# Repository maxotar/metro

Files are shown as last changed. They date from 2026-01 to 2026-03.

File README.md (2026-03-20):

# Metro - Vibrating Metronome Wearable

A compact wearable metronome device that provides haptic feedback for keeping time. Perfect for musicians, dancers, and other performers who need portable tempo guidance.

## Project Metadata

- **Project Name:** Metro
- **Type:** Wearable Device
- **Primary Function:** Vibrating Metronome
- **Target MCU:** ATtiny1616
- **CPU Frequency:** 4 MHz
- **Battery:** 302025 LiPo
- **Charging:** Smart ring magnetic pogo pin connector

## Project Structure

### `/electrical`
PCB design files, schematics, and component information
- KiCad project files (.kicad_sch, .kicad_pcb)
- Component library with footprints and datasheets
- Fabrication and production files (BOM, designators, netlist)

### `/src`
Firmware for the ATtiny1616 microcontroller
- `main.cpp` - Main program entry point
- `i2c.cpp` - I2C communication library

### `/mechanical`
Enclosure and mechanical design
- `Case.step` - 3D model of the device case
- [Onshape CAD](https://cad.onshape.com/documents/80829a8af30c2a989428d6ff/w/00026b4066893ecc4d2da063/e/4930d11ba89da00962c1ae8d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) - Full source CAD file

**3D Printing Specifications:**
- Printer: Bambu Lab A1
- Material: Matte white PLA
- Bed: Smooth PEI surface
- Nozzle: 0.2 mm
- Layer height: 0.06 mm (high quality)
- Print method: Parts printed individually (case, back cap, buttons) for quality assurance

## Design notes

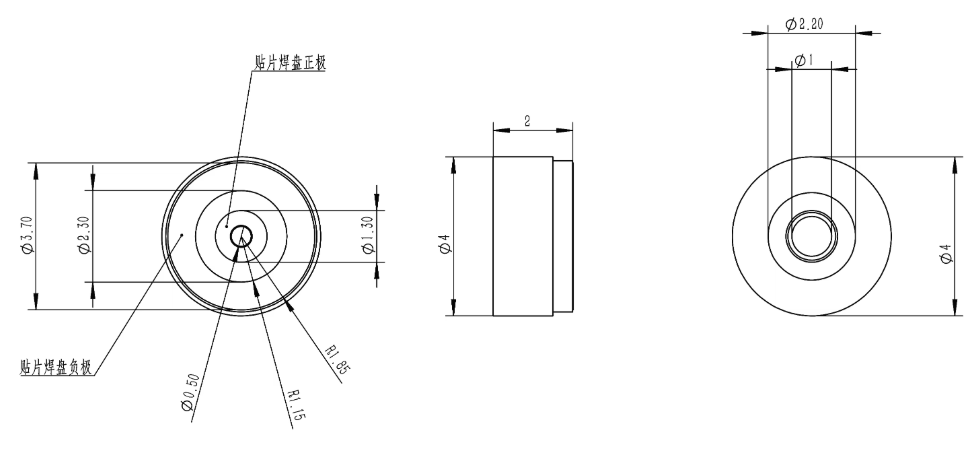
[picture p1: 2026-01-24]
mechanical/Power Connector.PNG

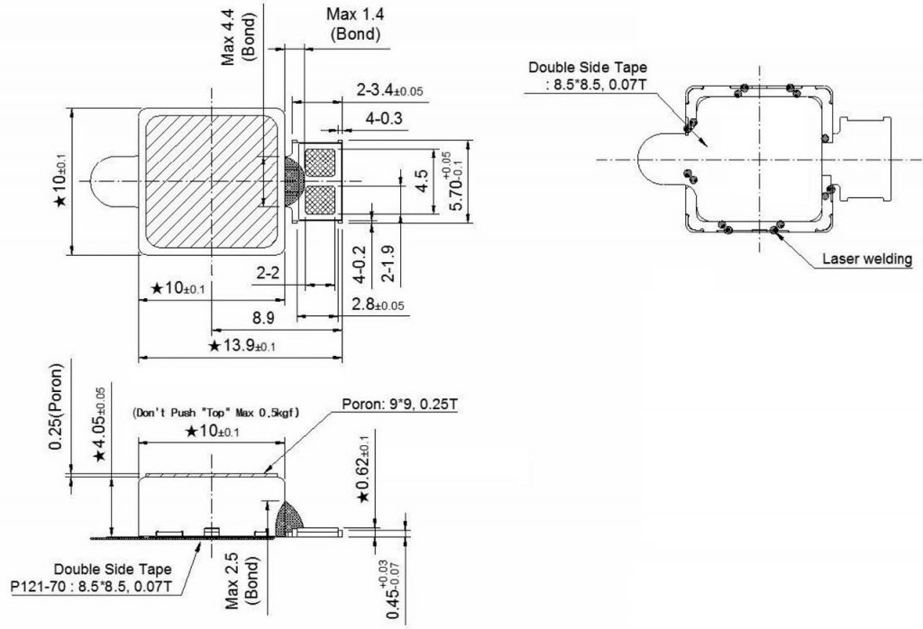
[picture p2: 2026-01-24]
mechanical/LRA VLV101040A.jpg

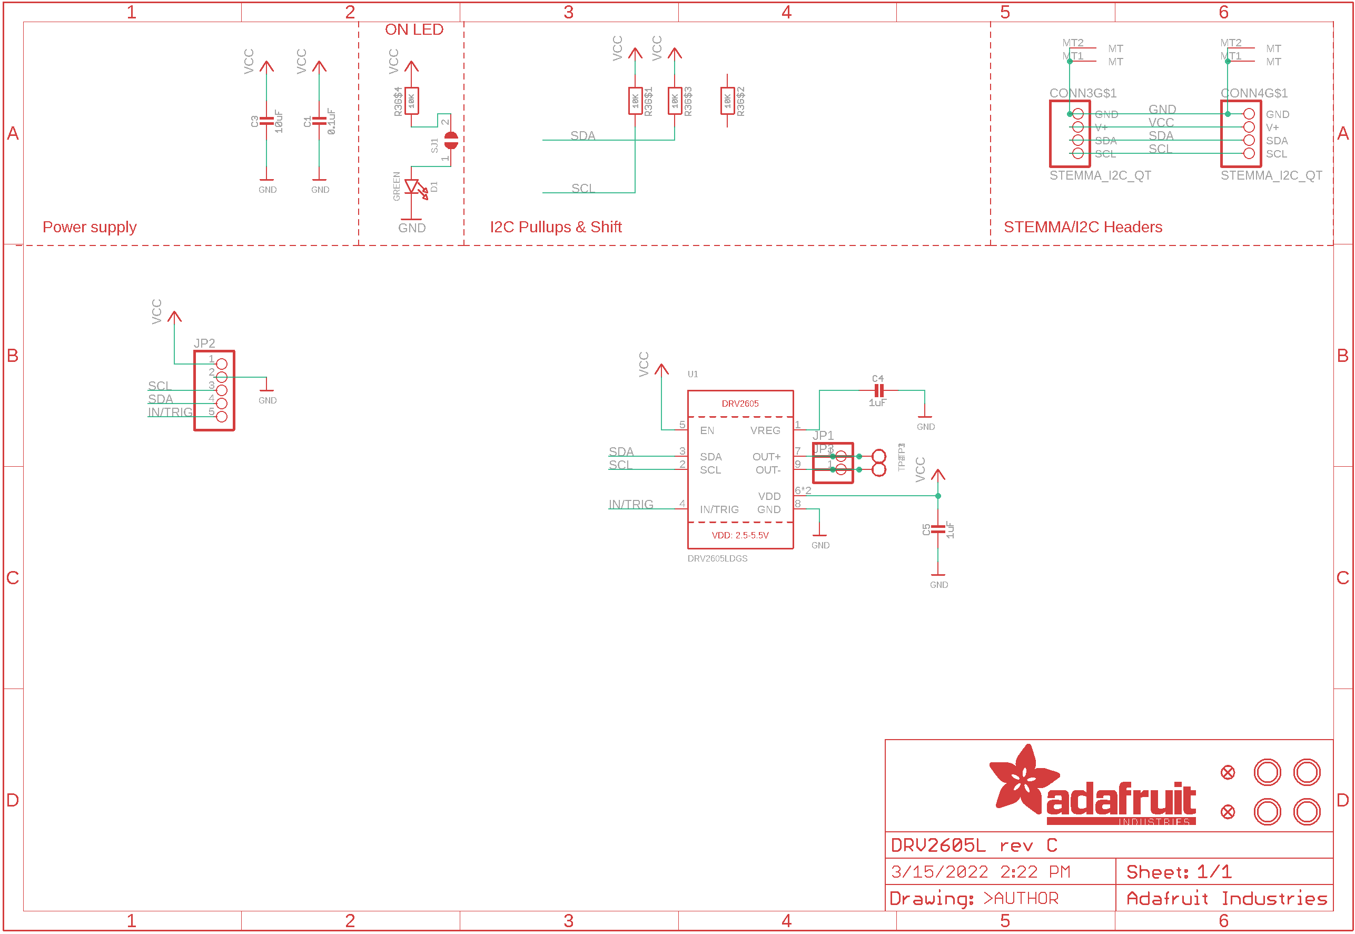
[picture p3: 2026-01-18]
electrical/references/Schematic Adafruit DRV2605L.png

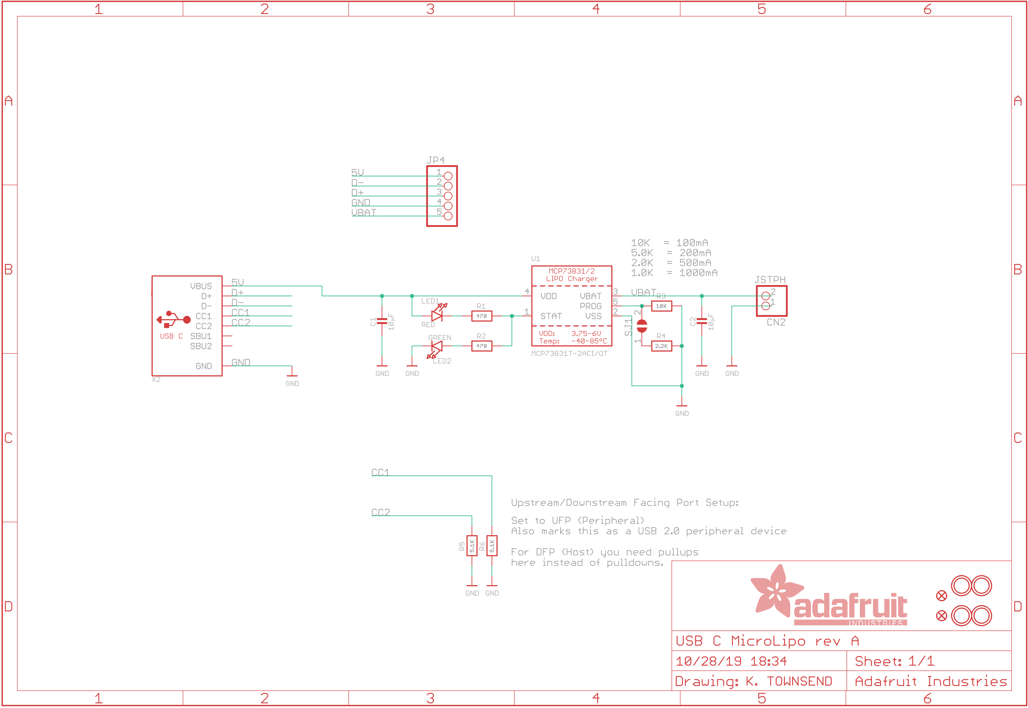
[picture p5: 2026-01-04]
electrical/references/Schematic Adafruit LiPo Charger.png

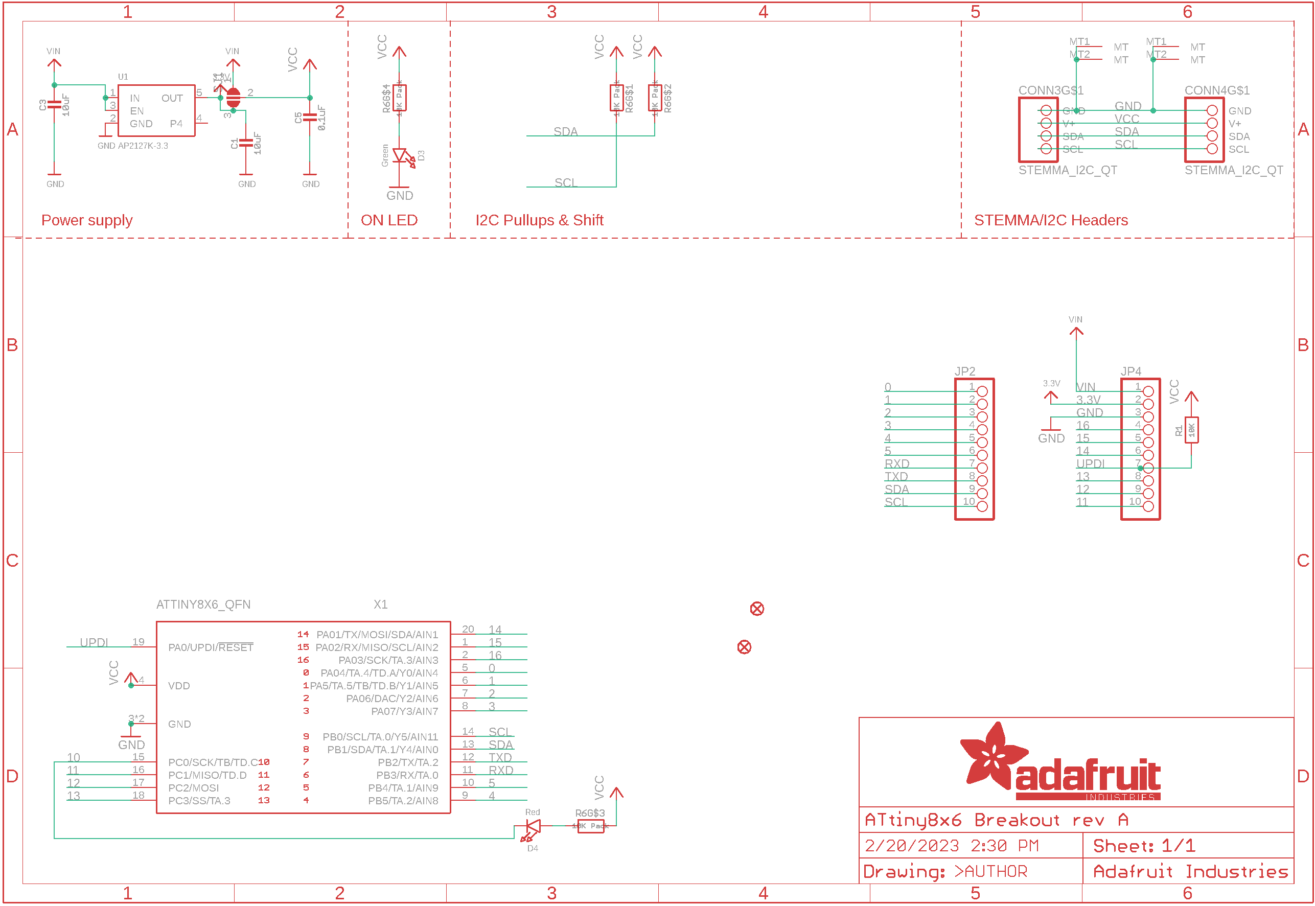
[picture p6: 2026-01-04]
electrical/references/Schematic Adafruit ATTiny1616 Breakout.png

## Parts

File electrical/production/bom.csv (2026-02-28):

Designator | Footprint | Quantity | Value | LCSC Part #
C1, C4, C7 | 0603 | 3 | 1μF
C2 | 0603 | 1 | 100nF
C3, C5, C6 | 0603 | 3 | 10μF
D1, D2, D3, D4, D5, D6 | Custom LTST-C230KRKT | 6 | Red | C125107
D7 | D_SMA | 1 | D_Schottky
R1, R2, R3, R4, R5, R9 | 0603 | 6 | 2k2
R6, R7 | 0603 | 2 | 4k7
R8 | 0603 | 1 | 33k
S1, S2, S3 | SW_EVQ-P7C01P | 3 | EVQ-P7C01P | C388883
U1 | VQFN20_REB_MCH | 1 | ATTINY1616-MN | C507118
U2 | SOT-23-5 | 1 | MCP73831T-2ACI/OT | C424093
U3 | VSSOP-10_3x3mm_P0.5mm | 1 | DRV2605LDGS | C527464

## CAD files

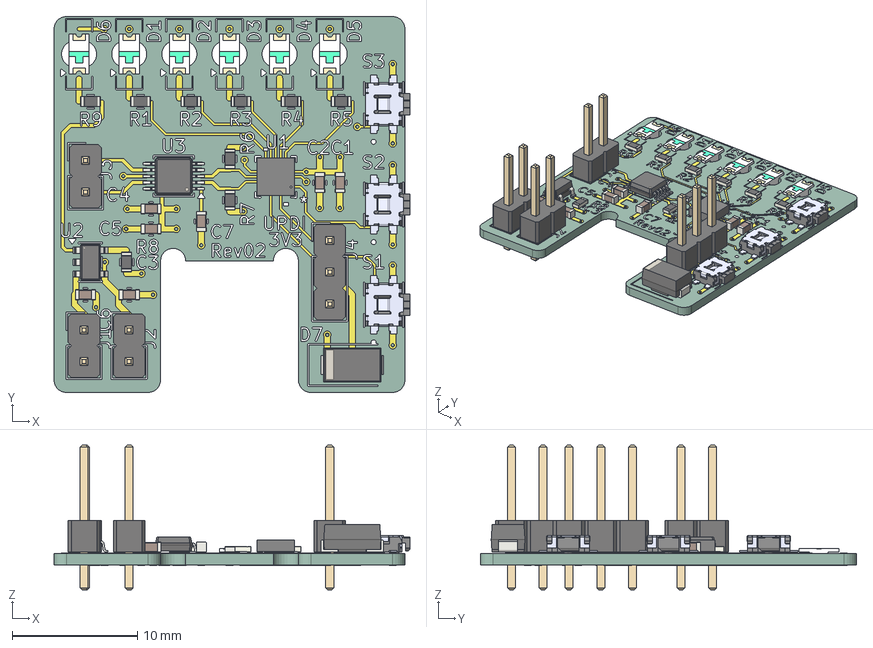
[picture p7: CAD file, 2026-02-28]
electrical/metro.step
28.4 x 30.0 x 11.5 mm
kicad_embedded_71B7471FF4199D6E1FC5C76A907E5594 x 6
EVQ-P7C01P x 3
C_0603_1608Metric x 7
SOT-23-5
PinHeader_1x02_P2.54mm_Vertical x 3
R_0603_1608Metric x 9
VSSOP-10_3x3mm_P0.5mm
kicad_embedded_9E333CD9FCD94FAEA26B531ADEA9CC1E
PinHeader_1x03_P2.54mm_Vertical
D_SMA
metro_copper
metro_via
metro_silkscreen
metro_PCB

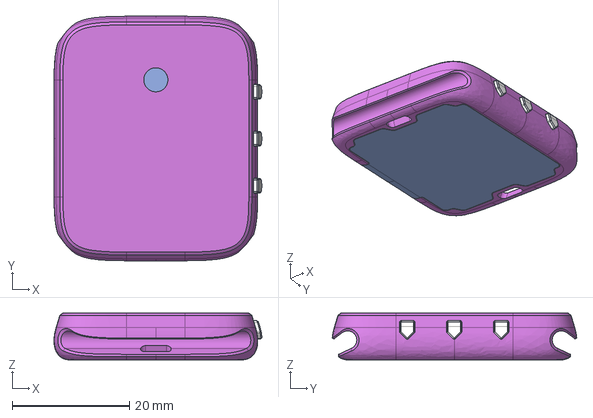
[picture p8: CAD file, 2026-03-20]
mechanical/Case.step
35.4 x 41.7 x 8.00 mm

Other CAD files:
electrical/metro.3mf

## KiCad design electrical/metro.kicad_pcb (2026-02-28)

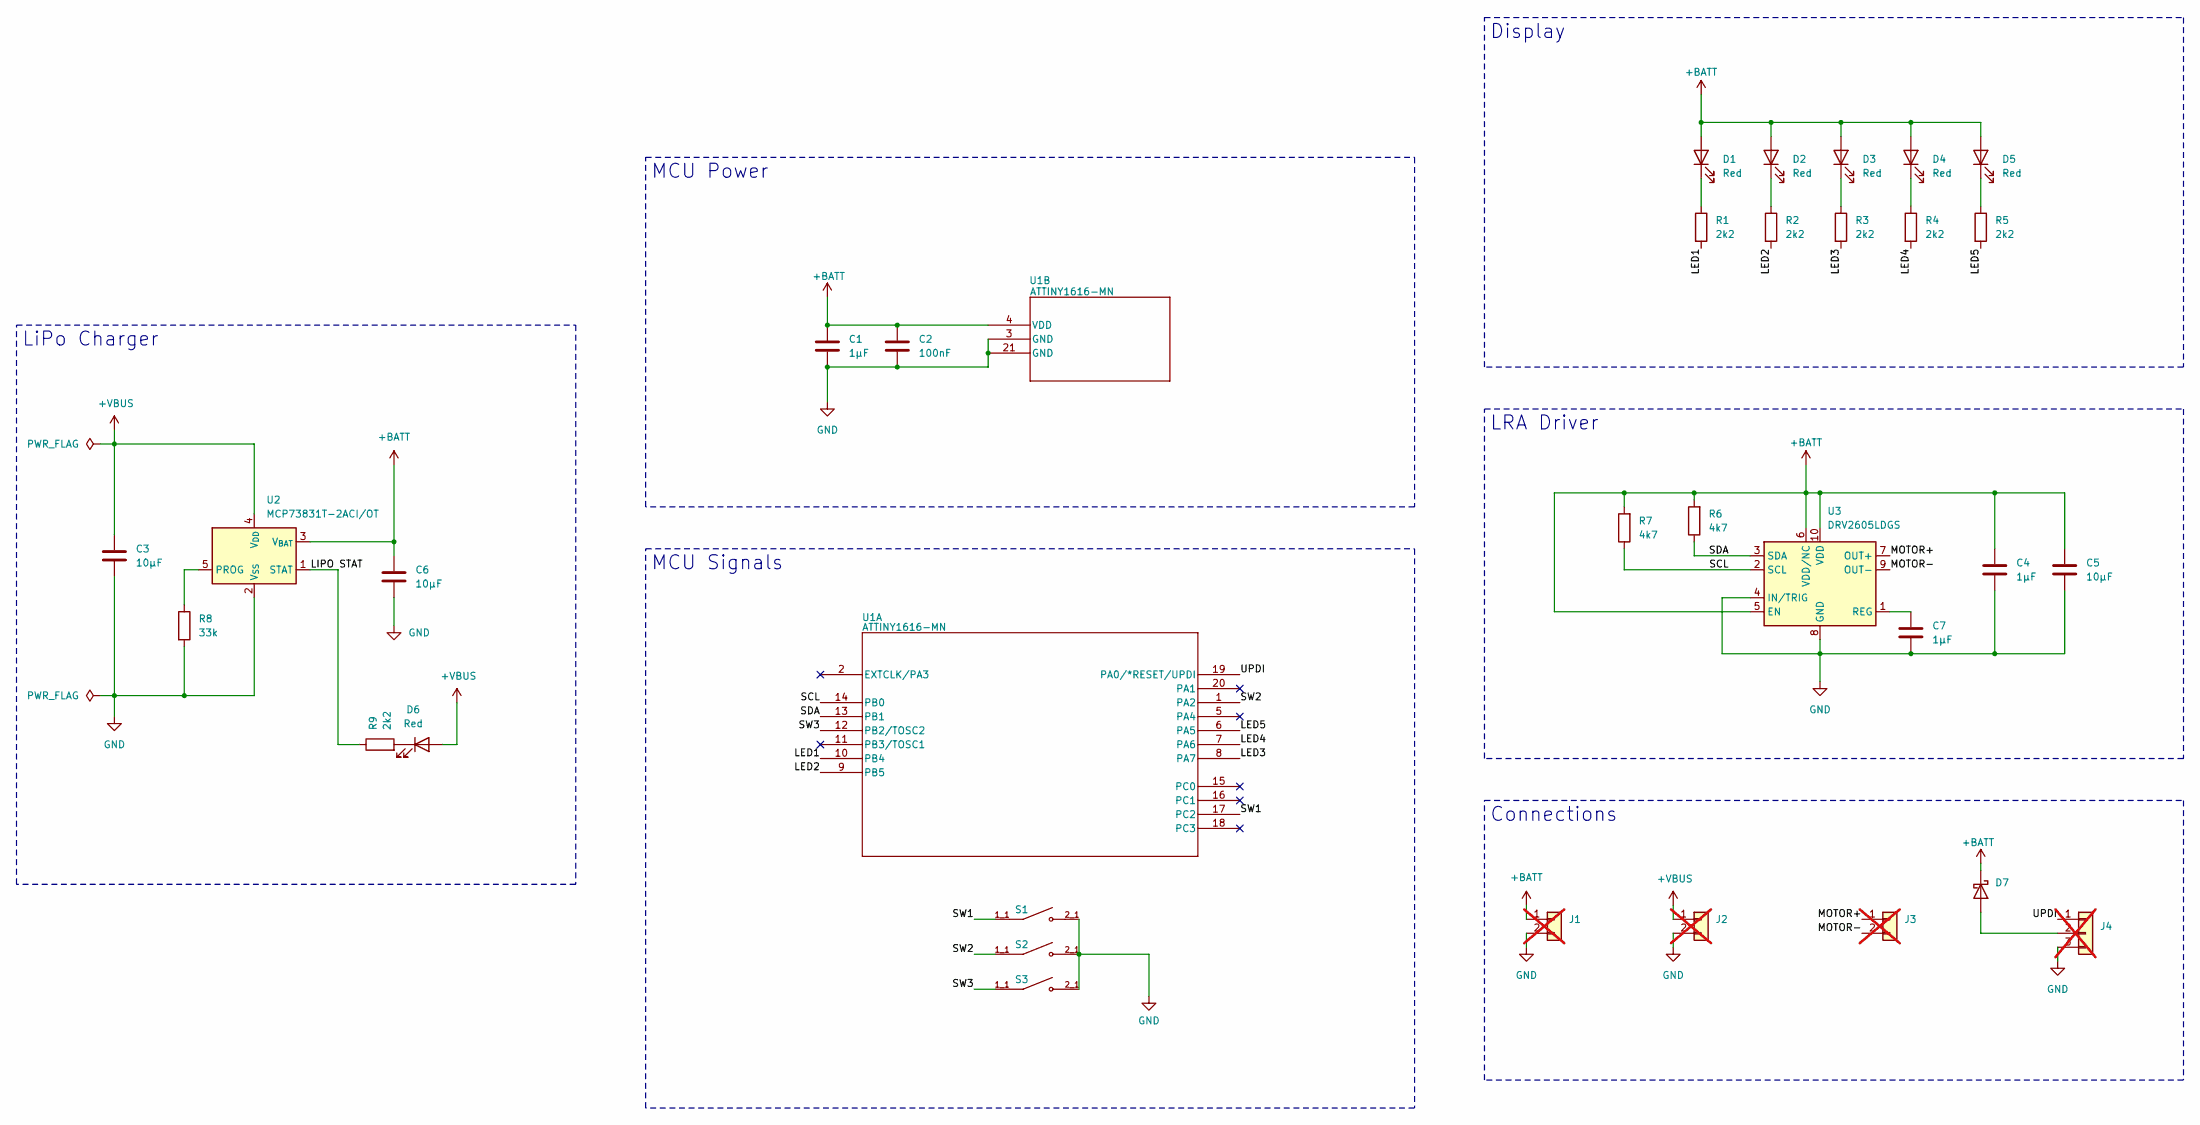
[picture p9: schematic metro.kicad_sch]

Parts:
C1, C4, C7: 1μF; C_0603_1608Metric_Pad1.08x0.95mm_HandSolder
C2: 100nF; C_0603_1608Metric_Pad1.08x0.95mm_HandSolder
C3, C5, C6: 10μF; C_0603_1608Metric_Pad1.08x0.95mm_HandSolder
D1, D2, D3, D4, D5, D6: Red; Custom LTST-C230KRKT; LCSC PN C125107
D7: D_Schottky; D_SMA
J1, J2, J3: Conn_01x02; PinHeader_1x02_P2.54mm_Vertical; not fitted
J4: Conn_01x03; PinHeader_1x03_P2.54mm_Vertical; not fitted
R1, R2, R3, R4, R5, R9: 2k2; R_0603_1608Metric_Pad0.98x0.95mm_HandSolder
R6, R7: 4k7; R_0603_1608Metric_Pad0.98x0.95mm_HandSolder
R8: 33k; R_0603_1608Metric_Pad0.98x0.95mm_HandSolder
S1, S2, S3: EVQ-P7C01P; SW_EVQ-P7C01P; LCSC PN C388883
U1: ATTINY1616-MN; VQFN20_REB_MCH; LCSC PN C507118
U2: MCP73831T-2ACI/OT; SOT-23-5; LCSC PN C424093
U3: DRV2605LDGS; VSSOP-10_3x3mm_P0.5mm; LCSC PN C527464

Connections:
+BATT: C1.1, C2.1, C4.1, C5.1, C6.1, D1.2 (A), D2.2 (A), D3.2 (A), D4.2 (A), D5.2 (A), D7.1 (K), J1.1, R6.2, R7.2, U1.4 (VDD), U2.3 (V_{BAT}), U3.5 (EN), U3.6 (VDD/NC), U3.10 (VDD)
+VBUS: C3.1, D6.2 (A), J2.1, U2.4 (V_{DD})
/LED1: R1.2, U1.10 (PB4)
/LED2: R2.2, U1.9 (PB5)
/LED3: R3.2, U1.8 (PA7)
/LED4: R4.2, U1.7 (PA6)
/LED5: R5.2, U1.6 (PA5)
/LIPO STAT: R9.1, U2.1 (STAT)
/MOTOR+: J3.1, U3.7 (OUT+)
/MOTOR-: J3.2, U3.9 (OUT-)
/SCL: R7.1, U1.14 (PB0), U3.2 (SCL)
/SDA: R6.1, U1.13 (PB1), U3.3 (SDA)
/SW1: S1.1_1, S1.1_2, U1.17 (PC2)
/SW2: S2.1_1, S2.1_2, U1.1 (PA2)
/SW3: S3.1_1, S3.1_2, U1.12 (PB2/TOSC2)
/UPDI: J4.1, U1.19 (PA0/*RESET/UPDI)
GND: C1.2, C2.2, C3.2, C4.2, C5.2, C6.2, C7.2, J1.2, J2.2, J4.3, R8.2, S1.2_1, S1.2_2, S2.2_1, S2.2_2, S3.2_1, S3.2_2, U1.3 (GND), U1.21 (GND), U2.2 (V_{SS}), U3.4 (IN/TRIG), U3.8 (GND)
unnamed: D1.1 (K), R1.1
unnamed: D2.1 (K), R2.1
unnamed: D3.1 (K), R3.1
unnamed: D4.1 (K), R4.1
unnamed: D5.1 (K), R5.1
unnamed: D6.1 (K), R9.2
unnamed: D7.2 (A), J4.2
unnamed: R8.1, U2.5 (PROG)
unnamed: C7.1, U3.1 (REG)

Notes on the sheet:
MCU Signals
Display
LiPo Charger
LRA Driver
MCU Power
Connections

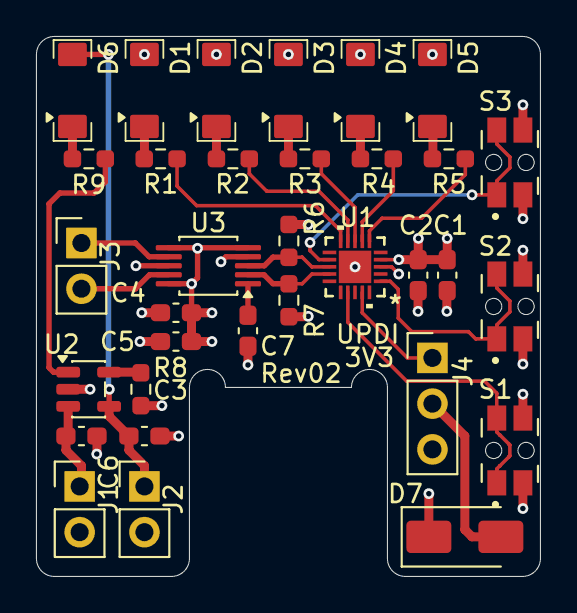
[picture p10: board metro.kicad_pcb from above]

Board: 4 copper layers, 28.0 x 30.0 mm, 33 parts (0 on the bottom side), 26 nets.

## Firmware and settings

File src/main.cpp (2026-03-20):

#include <avr/io.h>
#include <avr/interrupt.h>
#include <avr/sleep.h>
#include <avr/cpufunc.h>
#include <util/atomic.h>
#include <util/delay.h>
#include <stdint.h>
#include <stdbool.h>
#include "i2c.h"

/* ============================================================================
   ATtiny1616 Pin Usage (20-pin VQFN)
   ============================================================================
   Pin    | Function    | Usage          | Direction | Notes
   -------+-------------+----------------+-----------+-------------------------
   VDD  4 | Power       | Power supply   | -         | Connect to 3.3V/5V
   GND  3 | Ground      | Ground         | -         | Common ground
   PA0 19 | UPDI        | Programming    | -         | Reserved for UPDI
   PA1 20 | -           | FREE           | -         | Available
   PA2  1 | SW2         | Play/Pause     | Input     | Internal pullup, FALLING
   PA3  2 | -           | FREE           | -         | Available
   PA4  5 | -           | FREE           | -         | Available
   PB4 10 | LED1 (LSB)  | LED bit 0      | Output    | Active low
   PB5  9 | LED2        | LED bit 1      | Output    | Active low
   PA7  8 | LED3        | LED bit 2      | Output    | Active low
   PB0 14 | TWI0 SCL    | I2C Clock      | I2C       | 4.7kΩ pullup
   PB1 13 | TWI0 SDA    | I2C Data       | I2C       | 4.7kΩ pullup
   PB2 12 | SW3         | Increase BPM   | Input     | Internal pullup, FALLING
   PB3 11 | -           | FREE           | -         | Available
   PA5  6 | LED5 (MSB)  | LED bit 4      | Output    | Active low
   PA6  7 | LED4        | LED bit 3      | Output    | Active low
   PC0 15 | -           | FREE           | -         | Available
   PC1 16 | -           | FREE           | -         | Available
   PC2 17 | SW1         | Decrease BPM   | Input     | Internal pullup, FALLING
   PC3 18 | -           | FREE           | -         | Available

   Used: 11 pins (3 buttons + 5 BPM LEDs + 2 I2C + 1 UPDI)
   Free:  7 pins (PA1, PA3, PA4, PB3, PC0, PC1, PC3)
   Power: 2 pins (VDD, GND)
   Total: 20
   ============================================================================ */

typedef struct
{
  uint8_t pinMask;
  volatile PORT_t *port;
  volatile uint8_t *pinCtrl;
  uint8_t taskIndex;
  void (*onPress)(void);
} Button;

typedef struct
{
  uint32_t timeDue; /* 32‑bit absolute tick count, extended in software */
  uint8_t flags;
  void (*callback)(void *ctx);
  void *context;
} Task;

static void task_play(void *ctx);
static void task_pause(void *ctx);
static void task_haptic_standby(void *ctx);
static void task_hide_bpm(void *ctx);
static void task_debounce(void *ctx);
static void action_dec(void);
static void action_inc(void);
static void action_play_pause(void);

enum TaskIndex
{
  TASK_BTN_DEC_DEBOUNCE,
  TASK_BTN_PLAY_DEBOUNCE,
  TASK_BTN_INC_DEBOUNCE,
  TASK_PLAY,
  TASK_HAPTIC_STANDBY,
  TASK_HIDE_BPM,
  TASK_PAUSE,
  NUM_TASKS
};

static Button buttons[] = {
    {PIN2_bm, &PORTC, &PORTC.PIN2CTRL, TASK_BTN_DEC_DEBOUNCE, action_dec},         // SW1 - PC2 - Decrease BPM
    {PIN2_bm, &PORTA, &PORTA.PIN2CTRL, TASK_BTN_PLAY_DEBOUNCE, action_play_pause}, // SW2 - PA2 - Play/Pause
    {PIN2_bm, &PORTB, &PORTB.PIN2CTRL, TASK_BTN_INC_DEBOUNCE, action_inc},         // SW3 - PB2 - Increase BPM
};

/* software-extended 32‑bit RTC tick counter; incremented on every
   16‑bit overflow so that rtc_ticks + RTC.CNT gives a monotonic 32‑bit
   timebase.  using a wider time base removes the half‑range ambiguity
   that caused the low‑tempo buzzing. */
static volatile uint32_t rtc_ticks = 0;

static Task tasks[NUM_TASKS] = {
    {0, 0, task_debounce, &buttons[0]}, // TASK_BTN_DEC_DEBOUNCE
    {0, 0, task_debounce, &buttons[1]}, // TASK_BTN_PLAY_DEBOUNCE
    {0, 0, task_debounce, &buttons[2]}, // TASK_BTN_INC_DEBOUNCE
    {0, 0, task_play, 0},               // TASK_PLAY
    {0, 0, task_haptic_standby, 0},     // TASK_HAPTIC_STANDBY
    {0, 0, task_hide_bpm, 0},           // TASK_HIDE_BPM
    {0, 0, task_pause, 0}               // TASK_PAUSE
};

// Macros
#define NUM_BUTTONS (sizeof(buttons) / sizeof(Button))
#define TASK_PENDING (1 << 0)

// BPM Display LEDs (5 bits, scaled by 5) - all active low
// LED5 is MSB (bit 4) on PA5, LED4 bit 3 on PA6, LED3 bit 2 on PA7.
// LED2 bit 1 on PB5, LED1 is LSB bit 0 on PB4.
// Weighted values: PA5=80, PA6=40, PA7=20, PB5=10, PB4=5.
#define LED5_PIN PIN5_bm // PA5 - bit 4 (MSB)
#define LED4_PIN PIN6_bm // PA6 - bit 3
#define LED3_PIN PIN7_bm // PA7 - bit 2
#define LED2_PIN PIN5_bm // PB5 - bit 1
#define LED1_PIN PIN4_bm // PB4 - bit 0 (LSB)

// Timing constants (in RTC ticks at 32kHz, 1 tick = 0.030517578125 ms)
#define DEBOUNCE_DELAY 1966   // ~60 ms
#define HAPTIC_DRIVE_MS 393   // ~12 ms
#define LED_ON_DURATION 16384 // ~500 ms

#define BPM_INCREMENT 5
#define BPM_MIN 40
#define BPM_MAX 155
#define BPM_STEPS (((BPM_MAX - BPM_MIN) / BPM_INCREMENT) + 1)

static const uint16_t bpm_ticks[BPM_STEPS] = {
    49152,
    43690,
    39321,
    35746,
    32768,
    30247,
    28086,
    26214,
    24576,
    23130,
    21845,
    20695,
    19660,
    18724,
    17873,
    17096,
    16384,
    15728,
    15123,
    14563,
    14043,
    13556,
    13107,
    12684,
};

static inline uint16_t ticks_for_bpm(uint16_t bpm)
{
  if (bpm < BPM_MIN)
    bpm = BPM_MIN;
  else if (bpm > BPM_MAX)
    bpm = BPM_MAX;
  return bpm_ticks[(bpm - BPM_MIN) / BPM_INCREMENT];
}

static inline uint8_t min_u8(uint8_t a, uint8_t b)
{
  return a < b ? a : b;
}

static inline uint8_t max_u8(uint8_t a, uint8_t b)
{
  return a > b ? a : b;
}

// DRV2605L I2C address and registers used in this firmware
#define DRV2605L_ADDR 0x5A
#define DRV2605L_REG_MODE 0x01
#define DRV2605L_REG_RTPIN 0x02
#define DRV2605L_REG_CONTROL1 0x1B
#define DRV2605L_REG_CONTROL3 0x1D
#define DRV2605L_REG_FEEDBACK 0x1A
#define DRV2605L_REG_CLAMP_VOLT 0x17

// DRV2605L operating modes (MODE register values)
#define DRV2605L_MODE_NORMAL 0x00  // Active - registers writable, drive stage enabled
#define DRV2605L_MODE_RTP 0x05     // Real-Time Playback - amplitude set by RTPIN register
#define DRV2605L_MODE_STANDBY 0x40 // Low-power standby - drive disabled, registers retained

static uint8_t bpm = 100;

static void init_clock(void)
{
  // Prescaler DIV4 for 4MHz (16MHz / 4)
  // PDIV = 1 (divide by 2^(PDIV+1) = 2^2 = 4), PEN = 1 (enable)
  _PROTECTED_WRITE(CLKCTRL.MCLKCTRLB, (1 << CLKCTRL_PDIV_gp) | CLKCTRL_PEN_bm);
}

static bool try_init_haptic_driver(void)
{
  // -----------------------------------------------------------------------------
  // DRV2605L + VLV101040A LRA initialization
  //
  // Motor: VLV101040A
  //  - Type: LRA, Z-axis
  //  - Size: 10 × 10 × 4 mm
  //  - Rated voltage: 2.5 Vrms
  //  - Resonant frequency: ~170 Hz
  //  - Usable bandwidth: ~140–300 Hz
  //  - Fast response: ~10 ms rise, ~40 ms fall (unbraked)
  //
  // Usage:
  //  - Wearable haptic metronome
  //  - Very short, strong "tick" pulses (~12 ms)
  //  - Fixed frequency, open-loop, RTP drive
  //  - Aggressive braking to suppress ring-down
  // -----------------------------------------------------------------------------

  // --- Exit standby / reset internal state ---
  // Required before writing most configuration registers
  if (!i2c_write_reg_u8(DRV2605L_ADDR, DRV2605L_REG_MODE, DRV2605L_MODE_NORMAL))
    return false;

  // --- Set LRA resonant frequency (~170 Hz) ---
  // CONTROL1 = Drive Time
  // DriveTime = (1 / (2 × f)) × 10000 − 1
  // For 170 Hz → ~28–29 → 0x1C
  //
  // This sets the waveform frequency for *all* RTP pulses
  if (!i2c_write_reg_u8(DRV2605L_ADDR, DRV2605L_REG_CONTROL1, 0x1C))
    return false;

  // --- Clamp voltage (attack strength) ---
  // Raised above rated voltage for very short pulses
  // ~3.6 V peak equivalent
  //
  // Safe because:
  //  - Pulse width is only ~12 ms
  //  - Duty cycle is extremely low (metronome use)
  if (!i2c_write_reg_u8(DRV2605L_ADDR, DRV2605L_REG_CLAMP_VOLT, 0xA5))
    return false;

  // --- Feedback / braking configuration ---
  // Bit 7 = 1 → LRA mode
  // Brake factor = 8× → fast stop, minimal ring-down
  // Loop gain = medium → stable, predictable response
  //
  // This is critical for making the vibration feel like a "tap"
  // instead of a buzz when mounted against skin.
  if (!i2c_write_reg_u8(DRV2605L_ADDR, DRV2605L_REG_FEEDBACK, 0xBC))
    return false;

  // --- Disable auto-resonance & force open-loop ---
  // Required because this LRA has unusually wide bandwidth
  // Auto-resonance causes frequency hunting and inconsistent pulses
  //
  // Bit 5 = 1 → disable auto-resonance
  // Bit 1 = 1 → bidirectional drive
  // Bit 0 = 1 → open-loop
  if (!i2c_write_reg_u8(DRV2605L_ADDR, DRV2605L_REG_CONTROL3, 0x23))
    return false;

  // --- Enter standby ---
  // haptic_trigger() exits standby and enters RTP mode for each pulse.
  // Registers are retained in standby, so init only needs to run once.
  if (!i2c_write_reg_u8(DRV2605L_ADDR, DRV2605L_REG_MODE, DRV2605L_MODE_STANDBY))
    return false;

  return true;
}

static void init_haptic_driver(void)
{
  // Allow DRV2605L internal POR to settle
  _delay_us(250);

  // Retry indefinitely - no error recovery path on a wearable, only recourse is battery pull
  while (1)
  {
    i2c_bus_recovery(); // clears stuck bus and calls init_i2c()

    if (try_init_haptic_driver())
    {
      i2c_shutdown();
      return;
    }

    i2c_shutdown();
    _delay_ms(10);
  }
}

static inline void rtc_wait_ready(void)
{
  while (RTC.STATUS > 0)
    ;
}

static void init_rtc(void)
{
  rtc_ticks = 0; /* start extended counter from zero */

  rtc_wait_ready();

  RTC.CTRLA = 0;
  rtc_wait_ready();

  RTC.CLKSEL = RTC_CLKSEL_INT32K_gc;
  rtc_wait_ready();

  RTC.INTFLAGS = RTC_OVF_bm | RTC_CMP_bm;

  RTC.CMP = 3276; // 100ms at 32.768kHz
  rtc_wait_ready();

  RTC.CTRLA = RTC_PRESCALER_DIV1_gc | RTC_RTCEN_bm | RTC_RUNSTDBY_bm;
  rtc_wait_ready();

  /* keep overflow interrupt enabled permanently; enable/disable only the
     compare bit when there are pending tasks */
  RTC.INTCTRL = RTC_CMP_bm | RTC_OVF_bm;
  rtc_wait_ready();
}

static void init_unused_pins_low_power(void)
{
  // PA1, PA3, PA4 are free (PA2=SW2, PA5-PA7=BPM LEDs)
  PORTA.OUTCLR = PIN1_bm | PIN3_bm | PIN4_bm;
  PORTA.DIRSET = PIN1_bm | PIN3_bm | PIN4_bm;
  PORTA.PIN1CTRL = PORT_ISC_INPUT_DISABLE_gc;
  PORTA.PIN3CTRL = PORT_ISC_INPUT_DISABLE_gc;
  PORTA.PIN4CTRL = PORT_ISC_INPUT_DISABLE_gc;

  // PB3 is free (PB2 is now SW3)
  PORTB.OUTCLR = PIN3_bm;
  PORTB.DIRSET = PIN3_bm;
  PORTB.PIN3CTRL = PORT_ISC_INPUT_DISABLE_gc;

  // PC0, PC1, PC3 are free (PC2 is now SW1)
  PORTC.OUTCLR = PIN0_bm | PIN1_bm | PIN3_bm;
  PORTC.DIRSET = PIN0_bm | PIN1_bm | PIN3_bm;
  PORTC.PIN0CTRL = PORT_ISC_INPUT_DISABLE_gc;
  PORTC.PIN1CTRL = PORT_ISC_INPUT_DISABLE_gc;
  PORTC.PIN3CTRL = PORT_ISC_INPUT_DISABLE_gc;
}

static void init_buttons(void)
{
  for (uint8_t i = 0; i < NUM_BUTTONS; i++)
  {
    buttons[i].port->DIRCLR = buttons[i].pinMask;
    *(buttons[i].pinCtrl) = PORT_PULLUPEN_bm | PORT_ISC_FALLING_gc;
  }
}

static inline void led_set(volatile PORT_t *port, uint8_t pinMask, bool on)
{
  if (on)
    port->OUTCLR = pinMask; // active low
  else
    port->OUTSET = pinMask; // off
}

static void init_leds(void)
{
  // Configure LED pins as outputs on PORTA (MSB bits: PA5, PA6, PA7)
  PORTA.DIRSET = LED5_PIN | LED4_PIN | LED3_PIN;
  PORTA.OUTSET = LED5_PIN | LED4_PIN | LED3_PIN; // Start HIGH (LEDs off - active low)

  // Configure LED pins as outputs on PORTB (LSB bits: PB4, PB5)
  PORTB.DIRSET = LED1_PIN | LED2_PIN;
  PORTB.OUTSET = LED1_PIN | LED2_PIN; // Start HIGH (LEDs off - active low)
}

static void show_bpm(void)
{
  // Scale BPM to a 5-bit display value: 0..31 represents BPM_MIN..BPM_MAX in steps of 5
  uint8_t scaled = bpm / 5;

  led_set(&PORTB, LED1_PIN, (scaled & 0x01) != 0);
  led_set(&PORTB, LED2_PIN, (scaled & 0x02) != 0);
  led_set(&PORTA, LED3_PIN, (scaled & 0x04) != 0);
  led_set(&PORTA, LED4_PIN, (scaled & 0x08) != 0);
  led_set(&PORTA, LED5_PIN, (scaled & 0x10) != 0);
}

static void schedule_task(uint8_t task, uint16_t delay)
{
  ATOMIC_BLOCK(ATOMIC_RESTORESTATE)
  {
    rtc_wait_ready();
    uint32_t now = rtc_ticks + RTC.CNT;
    tasks[task].timeDue = now + delay;
    tasks[task].flags |= TASK_PENDING;
  }
}

static void cancel_task(uint8_t task)
{
  ATOMIC_BLOCK(ATOMIC_RESTORESTATE)
  {
    tasks[task].flags &= ~TASK_PENDING;
  }
}

static void haptic_trigger(void)
{
  // -----------------------------------------------------------------------------
  // Generate one haptic "tick" using RTP drive
  //
  // Dynamics summary:
  //  - The LRA is a resonant mechanical system (~170 Hz)
  //  - Maximum perceived sharpness comes from:
  //      1) Hitting resonance hard (high initial acceleration)
  //      2) Letting it ring for ~2 cycles
  //      3) Actively braking to suppress tail vibration
  //
  // For a 170 Hz LRA:
  //  - Period ≈ 5.9 ms
  //  - 12 ms ≈ 2 cycles → strong but non-buzzy impulse
  //
  // This function assumes:
  //  - Frequency, clamp voltage, brake strength are already configured at init
  //  - Auto-resonance is disabled (open-loop operation)
  // -----------------------------------------------------------------------------

  // Bring up I2C just-in-time to minimize idle power
  init_i2c();

  // --- Wake the driver ---
  // MODE_NORMAL exits standby and clears internal state
  i2c_write_reg_u8(DRV2605L_ADDR, DRV2605L_REG_MODE, DRV2605L_MODE_NORMAL);

  // Short delay ensures the analog drive stage is fully awake
  _delay_us(250);

  // --- Enter Real-Time Playback (RTP) mode ---
  // In RTP mode:
  //  - CONTROL1 defines the vibration frequency (≈170 Hz)
  //  - RTPIN defines instantaneous drive amplitude
  //
  // This bypasses waveform libraries and gives cycle-level control
  i2c_write_reg_u8(DRV2605L_ADDR, DRV2605L_REG_MODE, DRV2605L_MODE_RTP);
  _delay_ms(1);

  // --- Apply drive ---
  // Full-scale RTP produces the strongest initial acceleration,
  // which dominates perceived intensity for short pulses
  i2c_write_reg_u8(DRV2605L_ADDR, DRV2605L_REG_RTPIN, 127);

  // Shut down I2C - the DRV2605L drives the LRA autonomously from the RTPIN
  // register value, no bus activity needed during the drive window.
  i2c_shutdown();

  // Schedule RTPIN=0 (brake) + standby after ~2 LRA cycles at 170 Hz.
  // The CPU is free to sleep in STANDBY mode until this fires.
  schedule_task(TASK_HAPTIC_STANDBY, HAPTIC_DRIVE_MS);
}

static void task_hide_bpm(void *ctx)
{
  (void)ctx;
  // blank all BPM LEDs (active low)
  PORTB.OUTSET = LED1_PIN | LED2_PIN;
  PORTA.OUTSET = LED3_PIN | LED4_PIN | LED5_PIN;
}

static void task_haptic_standby(void *ctx)
{
  (void)ctx;
  init_i2c();
  // RTPIN=0 engages braking - kills ring-down for a clean "tap" feel
  i2c_write_reg_u8(DRV2605L_ADDR, DRV2605L_REG_RTPIN, 0);
  // Return to low-power standby
  i2c_write_reg_u8(DRV2605L_ADDR, DRV2605L_REG_MODE, DRV2605L_MODE_STANDBY);
  i2c_shutdown();
}

static void task_play(void *ctx)
{
  (void)ctx;
  uint16_t ticks = ticks_for_bpm(bpm);
  schedule_task(TASK_PLAY, ticks);
  haptic_trigger();
}

static void task_pause(void *ctx)
{
  (void)ctx;
  cancel_task(TASK_PLAY);
  cancel_task(TASK_HAPTIC_STANDBY);
  task_hide_bpm(0);
  task_haptic_standby(0); // brake and standby unconditionally - harmless if motor already stopped
}

static void task_debounce(void *ctx)
{
  Button *btn = (Button *)ctx;

  // Clear any pending interrupt on this button pin.
  btn->port->INTFLAGS = btn->pinMask;

  // If the switch is still pressed (low), keep waiting; this avoids
  // bounce-induced repeat events while the user holds the button.
  if ((btn->port->IN & btn->pinMask) == 0)
  {
    schedule_task(btn->taskIndex, DEBOUNCE_DELAY);
    return;
  }

  // Button is released (high), re-enable falling-edge interrupt for next press.
  *(btn->pinCtrl) = PORT_PULLUPEN_bm | PORT_ISC_FALLING_gc;
}

static void action_dec(void)
{
  bpm = max_u8(bpm - BPM_INCREMENT, BPM_MIN);
  show_bpm();
  schedule_task(TASK_HIDE_BPM, LED_ON_DURATION);
}

static void action_inc(void)
{
  bpm = min_u8(bpm + BPM_INCREMENT, BPM_MAX);
  show_bpm();
  schedule_task(TASK_HIDE_BPM, LED_ON_DURATION);
}

static void action_play_pause(void)
{
  bool isPlaying;
  ATOMIC_BLOCK(ATOMIC_RESTORESTATE)
  {
    isPlaying = (tasks[TASK_PLAY].flags & TASK_PENDING);
  }

  if (!isPlaying)
  {
    show_bpm();
    schedule_task(TASK_HIDE_BPM, LED_ON_DURATION);
  }

  schedule_task(isPlaying ? TASK_PAUSE : TASK_PLAY, 0);
}

static bool process_tasks(void)
{
  bool ranAny = false;
  uint32_t now;

  ATOMIC_BLOCK(ATOMIC_RESTORESTATE)
  {
    rtc_wait_ready();
    now = rtc_ticks + RTC.CNT;
  }

  for (uint8_t i = 0; i < NUM_TASKS; i++)
  {
    bool run = false;
    ATOMIC_BLOCK(ATOMIC_RESTORESTATE)
    {
      if (tasks[i].flags & TASK_PENDING)
      {
        /* 32‑bit signed difference avoids ambiguity up to ±2³¹ ticks (≈ 21 hr
           at 32 kHz).  since now and timeDue are monotonic, the sign of the
           subtraction tells us whether the deadline has passed. */
        int32_t delta = (int32_t)(now - tasks[i].timeDue);
        if (delta >= 0)
        {
          tasks[i].flags &= ~TASK_PENDING;
          run = true;
        }
      }
    }

    if (run)
    {
      tasks[i].callback(tasks[i].context);
      ranAny = true;
    }
  }

  return ranAny;
}

static bool is_any_task_pending(void)
{
  ATOMIC_BLOCK(ATOMIC_RESTORESTATE)
  {
    for (uint8_t i = 0; i < NUM_TASKS; i++)
    {
      if (tasks[i].flags & TASK_PENDING)
      {
        return true;
      }
    }
  }
  return false;
}

static void prepare_next_wakeup(void)
{
  uint32_t now;
  uint32_t bestDelta = 0;
  uint16_t cmpVal = 0;
  bool found = false;

  ATOMIC_BLOCK(ATOMIC_RESTORESTATE)
  {
    rtc_wait_ready();
    now = rtc_ticks + RTC.CNT;
    for (uint8_t i = 0; i < NUM_TASKS; i++)
    {
      if (tasks[i].flags & TASK_PENDING)
      {
        uint32_t delta = tasks[i].timeDue - now;
        if (!found || delta < bestDelta)
        {
          bestDelta = delta;
          cmpVal = (uint16_t)tasks[i].timeDue;
          found = true;
        }
      }
    }
  }

  if (found)
  {
    rtc_wait_ready();
    RTC.CMP = cmpVal;
    rtc_wait_ready();
    RTC.INTFLAGS = RTC_CMP_bm;
    /* leave overflow interrupt enabled; only the compare bit is conditional */
    RTC.INTCTRL = RTC_CMP_bm | RTC_OVF_bm;
  }
  else
  {
    RTC.INTCTRL = RTC_OVF_bm;
  }
}

static void handle_button_isr(volatile PORT_t *port)
{
  uint8_t flags = port->INTFLAGS;
  port->INTFLAGS = flags;

  for (uint8_t i = 0; i < NUM_BUTTONS; i++)
  {
    if (buttons[i].port == port && (flags & buttons[i].pinMask))
    {
      *(buttons[i].pinCtrl) = PORT_PULLUPEN_bm | PORT_ISC_INTDISABLE_gc;
      if (buttons[i].onPress)
        buttons[i].onPress();
      schedule_task(buttons[i].taskIndex, DEBOUNCE_DELAY);
    }
  }
}

ISR(RTC_CNT_vect)
{
  uint8_t flags = RTC.INTFLAGS;
  RTC.INTFLAGS = flags; /* clear whatever caused the interrupt */
  if (flags & RTC_OVF_bm)
  {
    rtc_ticks += 0x10000; /* one 16‑bit wrap */
  }
  /* CMP flag is ignored here; prepare_next_wakeup() is invoked from
     the main loop after process_tasks() handles the due event. */
}

ISR(PORTA_PORT_vect)
{
  handle_button_isr(&PORTA);
}

ISR(PORTB_PORT_vect)
{
  handle_button_isr(&PORTB);
}

ISR(PORTC_PORT_vect)
{
  handle_button_isr(&PORTC);
}

int main(void)
{
  init_clock();
  init_rtc();
  init_unused_pins_low_power();
  init_buttons();
  init_leds();
  init_haptic_driver();

  sei();

  while (1)
  {
    while (process_tasks())
      ;

    prepare_next_wakeup();

    set_sleep_mode(is_any_task_pending()
                       ? SLEEP_MODE_STANDBY
                       : SLEEP_MODE_PWR_DOWN);

    cli();
    if (process_tasks())
    {
      sei();
      continue;
    }

    sleep_enable();
    sei();
    sleep_cpu();
    sleep_disable();
  }

  return 0;
}

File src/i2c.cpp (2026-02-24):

#include "i2c.h"
#include <avr/io.h>
#include <util/delay.h>

// F_CPU must be defined before including this file
#ifndef F_CPU
#error "F_CPU must be defined before including i2c.cpp"
#endif

static bool twi_wait(uint8_t mask)
{
    // Simple timeout to avoid lockups if the bus is held.
    for (uint16_t i = 0; i < 60000; i++)
    {
        if (TWI0.MSTATUS & mask)
        {
            return true;
        }
    }
    return false;
}

static bool twi_wait_idle(void)
{
    for (uint16_t i = 0; i < 60000; i++)
    {
        if (TWI0.MSTATUS & TWI_BUSSTATE_IDLE_gc)
        {
            return true;
        }
    }
    return false;
}

void init_i2c(void)
{
    // Configure pins as inputs (external pullups used)
    I2C_PORT.DIRCLR = I2C_SDA_PIN_bm | I2C_SCL_PIN_bm;

    // Disable before configuration.
    TWI0.MCTRLA = 0;

    // Baud rate with rise time compensation:
    // MBAUD = ((F_CPU/FREQ) - (F_CPU*T_RISE/1e9) - 10) / 2
    const uint32_t baud = ((F_CPU / I2C_SCL_HZ) - ((F_CPU * I2C_RISE_TIME_NS) / 1000000000UL) - 10) / 2;
    TWI0.MBAUD = (uint8_t)((baud > 255UL) ? 255UL : baud);

    // Force bus state to IDLE.
    TWI0.MSTATUS = TWI_BUSSTATE_IDLE_gc;

    // Enable TWI master.
    TWI0.MCTRLA = TWI_ENABLE_bm;
}

void i2c_shutdown(void)
{
    TWI0.MCTRLA = 0;
    TWI0.MCTRLB = 0;

    // Release pins as inputs - external pullups hold lines idle-high.
    // This leaves the bus in a valid idle state and avoids ~1.4 mA of
    // continuous pullup current that would flow if lines were driven low.
    I2C_PORT.DIRCLR = I2C_SDA_PIN_bm | I2C_SCL_PIN_bm;
}

bool i2c_write_bytes(uint8_t addr7, const uint8_t *data, uint8_t len)
{
    TWI0.MADDR = (uint8_t)(addr7 << 1);
    if (!twi_wait(TWI_WIF_bm))
        return false;
    if (TWI0.MSTATUS & (TWI_ARBLOST_bm | TWI_BUSERR_bm | TWI_RXACK_bm))
    {
        TWI0.MCTRLB = TWI_MCMD_STOP_gc;
        twi_wait_idle();
        return false;
    }

    for (uint8_t i = 0; i < len; i++)
    {
        TWI0.MDATA = data[i];
        if (!twi_wait(TWI_WIF_bm))
        {
            TWI0.MCTRLB = TWI_MCMD_STOP_gc;
            twi_wait_idle();
            return false;
        }
        if (TWI0.MSTATUS & TWI_RXACK_bm)
        {
            TWI0.MCTRLB = TWI_MCMD_STOP_gc;
            twi_wait_idle();
            return false;
        }
    }

    TWI0.MCTRLB = TWI_MCMD_STOP_gc;
    twi_wait_idle();
    return true;
}

bool i2c_write_reg_u8(uint8_t addr7, uint8_t reg, uint8_t value)
{
    uint8_t data[2] = {reg, value};
    return i2c_write_bytes(addr7, data, 2);
}

bool i2c_read_reg_u8(uint8_t addr7, uint8_t reg, uint8_t *value)
{
    // Write register address
    TWI0.MADDR = (uint8_t)(addr7 << 1);
    if (!twi_wait(TWI_WIF_bm))
    {
        TWI0.MCTRLB = TWI_MCMD_STOP_gc;
        twi_wait_idle();
        return false;
    }
    if (TWI0.MSTATUS & (TWI_ARBLOST_bm | TWI_BUSERR_bm | TWI_RXACK_bm))
    {
        TWI0.MCTRLB = TWI_MCMD_STOP_gc;
        twi_wait_idle();
        return false;
    }

    TWI0.MDATA = reg;
    if (!twi_wait(TWI_WIF_bm))
    {
        TWI0.MCTRLB = TWI_MCMD_STOP_gc;
        twi_wait_idle();
        return false;
    }
    if (TWI0.MSTATUS & TWI_RXACK_bm)
    {
        TWI0.MCTRLB = TWI_MCMD_STOP_gc;
        twi_wait_idle();
        return false;
    }

    // Repeated start + read
    TWI0.MADDR = (uint8_t)((addr7 << 1) | 0x01);
    if (!twi_wait(TWI_RIF_bm))
    {
        TWI0.MCTRLB = TWI_MCMD_STOP_gc;
        twi_wait_idle();
        return false;
    }
    if (TWI0.MSTATUS & (TWI_ARBLOST_bm | TWI_BUSERR_bm | TWI_RXACK_bm))
    {
        TWI0.MCTRLB = TWI_MCMD_STOP_gc;
        twi_wait_idle();
        return false;
    }

    // Read byte and NACK
    *value = TWI0.MDATA;
    TWI0.MCTRLB = TWI_ACKACT_NACK_gc | TWI_MCMD_STOP_gc;
    twi_wait_idle();
    return true;
}

void i2c_bus_recovery(void)
{
    // Disable TWI
    TWI0.MCTRLA = 0;

    // Configure SCL as output
    I2C_PORT.DIRSET = I2C_SCL_PIN_bm;

    // Generate up to 9 clock pulses
    for (uint8_t i = 0; i < 9; i++)
    {
        I2C_PORT.OUTCLR = I2C_SCL_PIN_bm;
        _delay_us(5);
        I2C_PORT.OUTSET = I2C_SCL_PIN_bm;
        _delay_us(5);

        // Check if SDA released
        if (I2C_PORT.IN & I2C_SDA_PIN_bm)
        {
            break;
        }
    }

    // Reconfigure as input and reinitialize
    I2C_PORT.DIRCLR = I2C_SCL_PIN_bm;
    init_i2c();
}

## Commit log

2026-01-04 add bulk of electrical project
    [TS-1088-AR02016--3DModel-STEP-269445.STEP, VQFN20_REB_MCH.step, metro.kicad_pcb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]
2026-01-15 Basic vibration with breakout board
    [metro.kicad_pcb, metro.kicad_sch]
2026-01-18 working with standby but on button2
2026-01-18 working with i2c stuff in it
2026-01-19 power down working, still only play button
2026-01-19 buttons work, slightly glitchy
    [main.cpp]
2026-01-19 Improve i2c functions, and button interrupts. add ERM i2c function
2026-01-24 Circuit mostly complete with driver
    [metro.kicad_pcb, metro.kicad_sch, metro.step]
2026-01-26 new led setup
    [TS-1088-AR02016--3DModel-STEP-269445.STEP, metro.kicad_pcb, metro.kicad_sch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]
2026-01-29 Routing done
    [bom.csv, designators.csv, metro.kicad_pcb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]
2026-01-29 shift things away from edges, remove dead tracks
    [bom.csv, metro.3mf, metro.kicad_pcb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]
2026-01-30 Improve led footprint
    [bom.csv, metro.kicad_pcb, metro.kicad_sch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]
2026-01-31 pcb purchased
    [metro.kicad_pcb, metro.step]
2026-02-24 remove status led
2026-02-25 rev 2 board. larger components
    [metro.kicad_pcb, metro.kicad_sch, metro.step]
2026-02-28 increase rtc lcok speed. order board rev 2
    [bom.csv, designators.csv, metro.kicad_pcb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]
2026-03-01 fix timing math and pinout bugs
    [main.cpp]
2026-03-20 fix led order, improve debounce
    [main.cpp]
2026-03-20 project completed!
    [Case.step]
